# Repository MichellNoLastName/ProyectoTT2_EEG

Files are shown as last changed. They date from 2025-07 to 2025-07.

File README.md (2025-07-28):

# EEG con Sensores Capacitivos de No Contacto

## 🧠 Descripción

Este proyecto consiste en el desarrollo de un prototipo para la adquisición de señales electroencefalográficas (EEG) utilizando sensores capacitivos de no contacto. El sistema incluye una interfaz gráfica desarrollada en LabVIEW que permite visualizar y guardar los datos adquiridos.

El propósito principal es contar con una alternativa no invasiva y cómoda para el monitoreo de actividad cerebral, útil para investigación biomédica y futuros desarrollos en interfaces cerebro-computadora.

## 🔧 Tecnologías utilizadas

- **Lenguaje C** – Programación de microcontroladores.
- **Arduino** – Pruebas iniciales y prototipado.
- **MPLAB X IDE** – Desarrollo en microcontroladores PIC.
- **LabVIEW** – Interfaz gráfica para visualización y almacenamiento de señales.
- **SolidWorks** – Diseño del headset 3D.
- **Autodesk EAGLE** – Diseño de las placas electrónicas.

## 🖼️ Capturas

### Placa electrónica del electrodo en 3D Vista superior
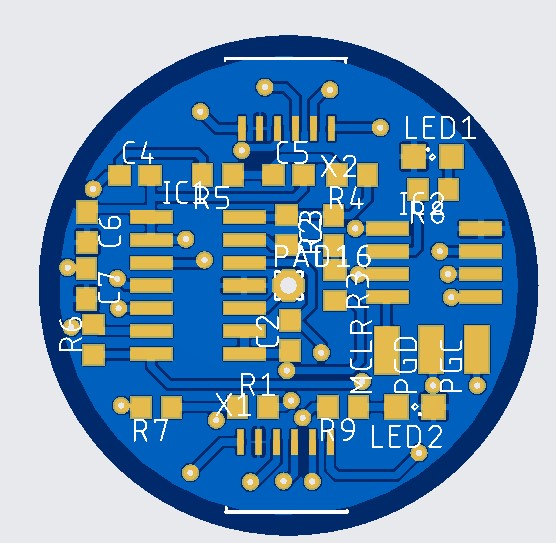
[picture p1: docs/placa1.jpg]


### Placa electrónica del electrodo en 3D Vista inferior
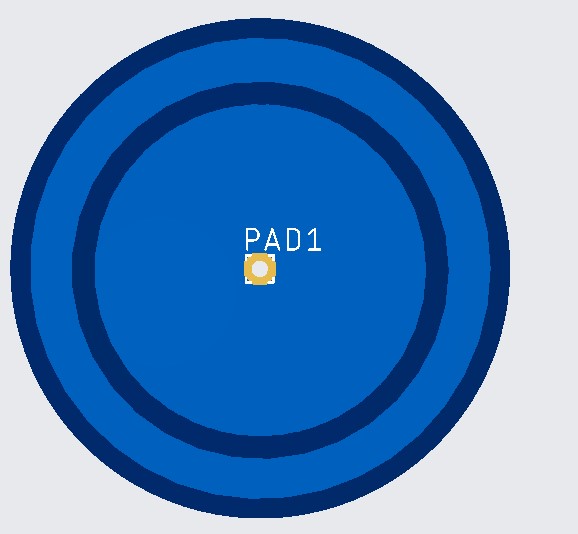
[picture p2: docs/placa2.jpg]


### Placa electrónica del electrodo fabricada
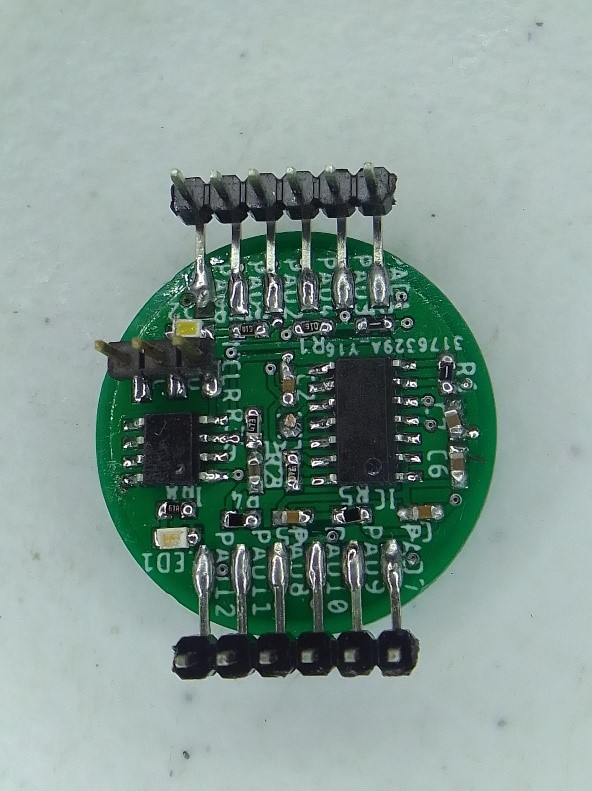
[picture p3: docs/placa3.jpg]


### Headset impreso en 3D
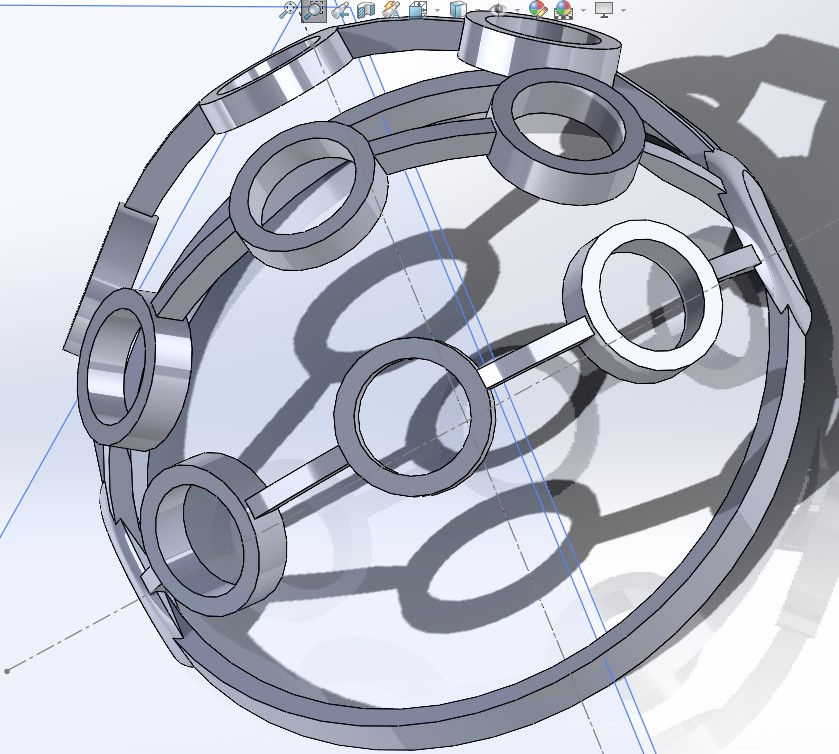
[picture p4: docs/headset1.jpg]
Headset EEG

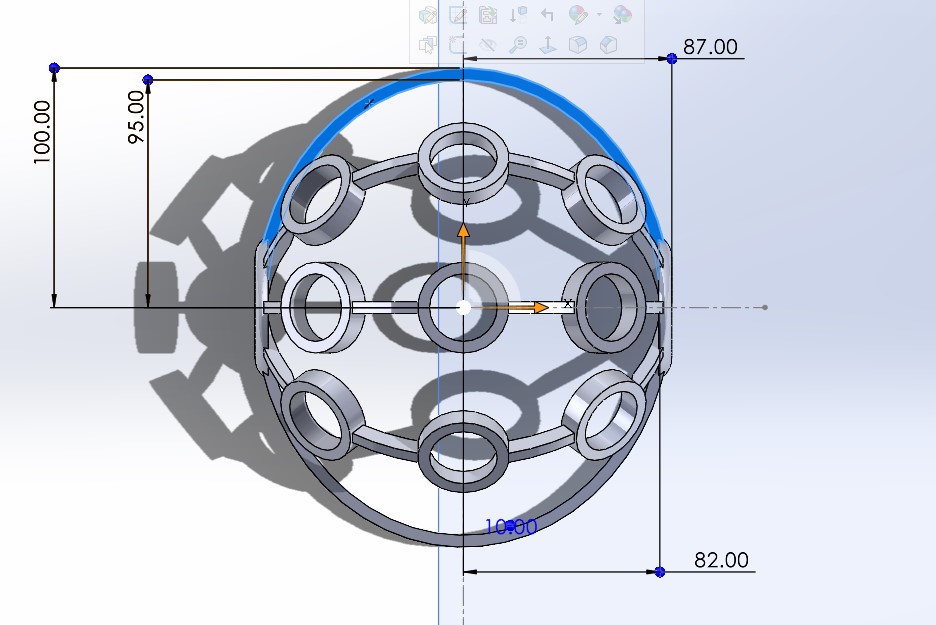
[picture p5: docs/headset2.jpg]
Headset EEG

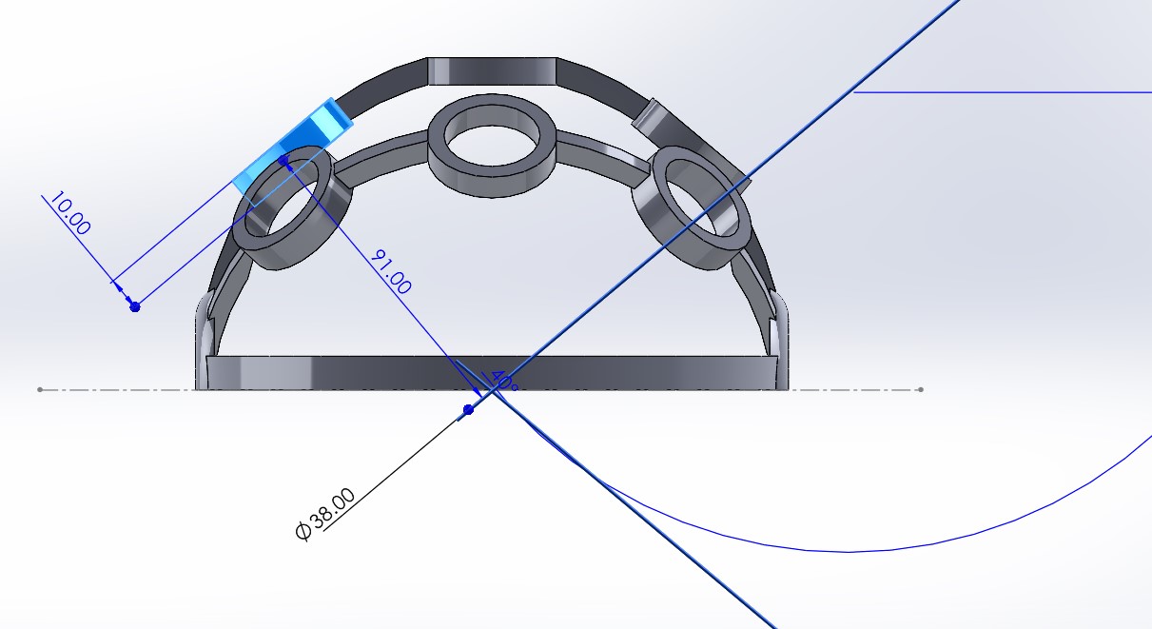
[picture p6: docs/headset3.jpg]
Headset EEG


## Pruebas realizadas
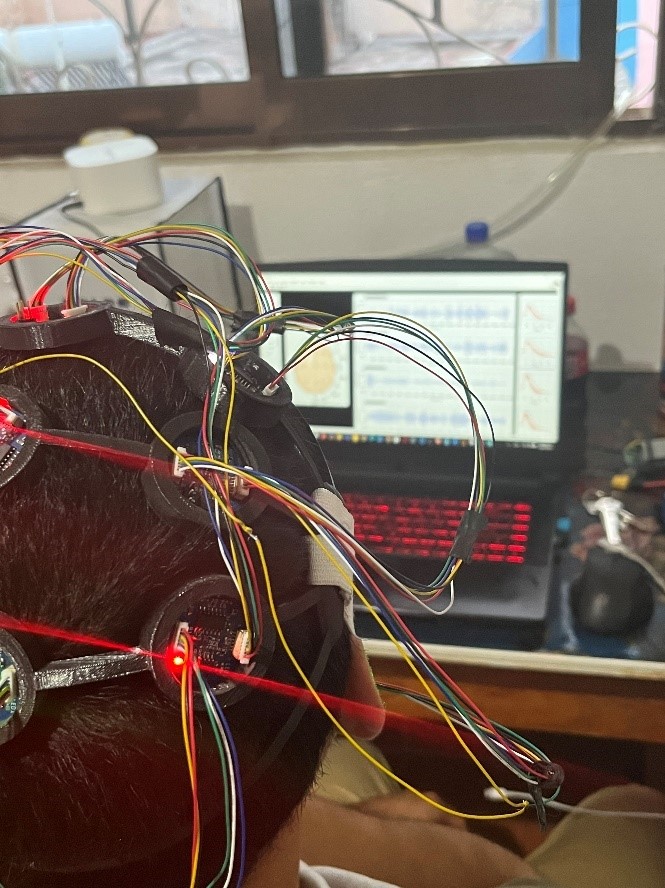
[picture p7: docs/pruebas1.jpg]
Pruebas EEG

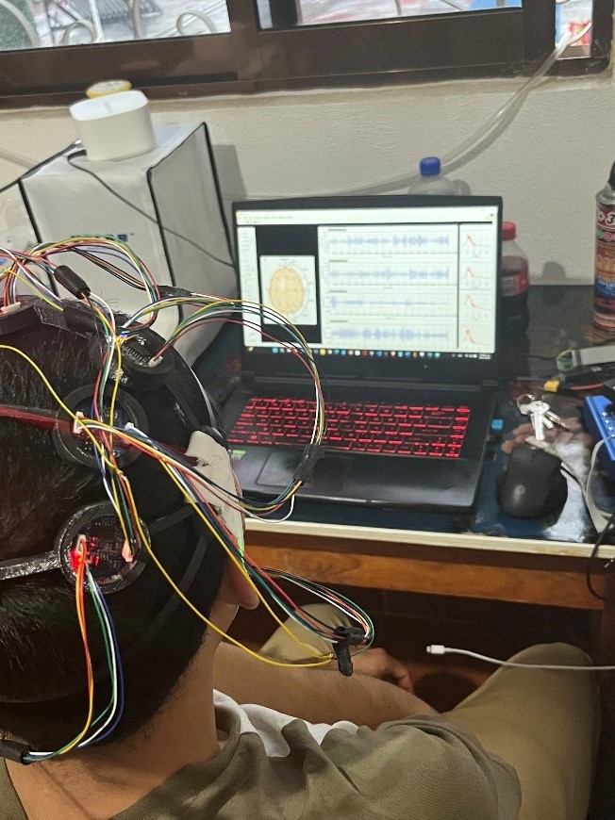
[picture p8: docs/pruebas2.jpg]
Pruebas EEG


### Interfaz de LabVIEW
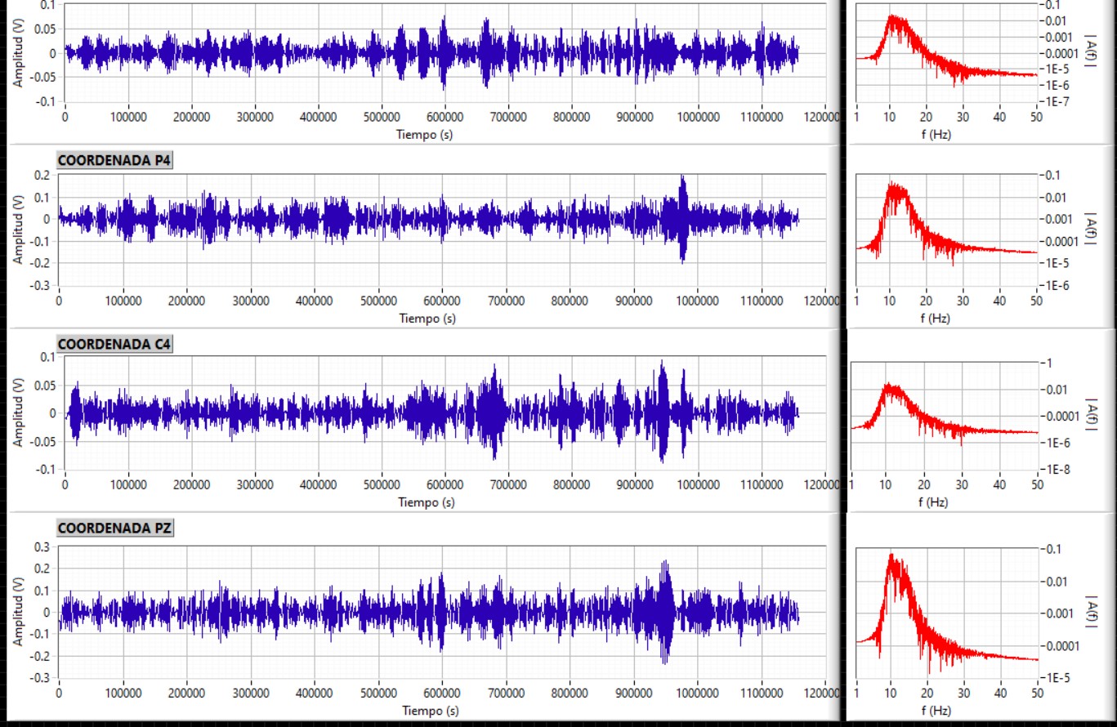
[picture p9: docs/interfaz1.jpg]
Interfaz LabVIEW

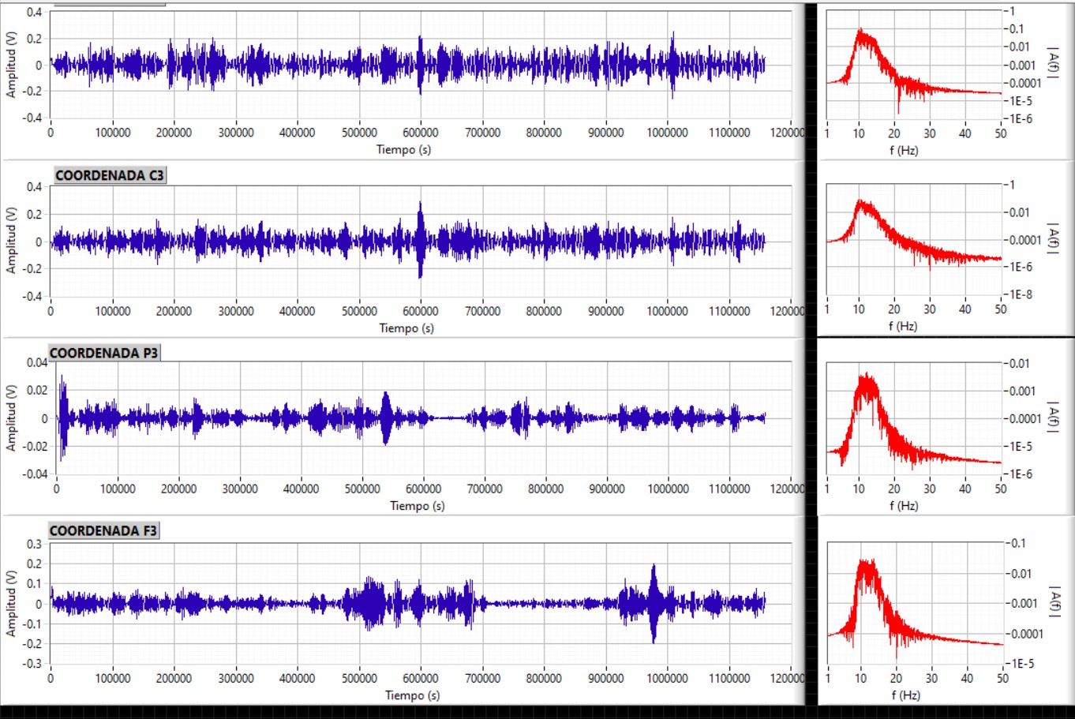
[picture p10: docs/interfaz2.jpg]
Interfaz LabVIEW


## 🚀 Instrucciones básicas de uso

1. **Conecta el sistema**: Alimenta los sensores y conecta el microcontrolador al PC.
2. **Ejecuta la interfaz LabVIEW**: Abre el archivo del proyecto y configura el puerto de comunicación.
3. **Adquiere señales**: Visualiza en tiempo real y guarda los datos cuando sea necesario.
4. **Exporta**: Los datos pueden exportarse como archivo `.csv` para análisis posterior.

## 🤝 Contribuciones

Este proyecto es parte de una tesis de ingeniería, pero estás invitado a contribuir con mejoras, sugerencias o ideas. Abre un Issue o un Pull Request si deseas colaborar.

## 🧾 Licencia

Este proyecto no tiene una licencia formal asignada. Si deseas usarlo con fines educativos o de investigación, puedes hacerlo con atribución.

## 👤 Autor

Michell Alejandro López Sierra  
[GitHub](https://github.com/) | [LinkedIn](https://linkedin.com/) | [Email](ingmichell5101@gmail.com)

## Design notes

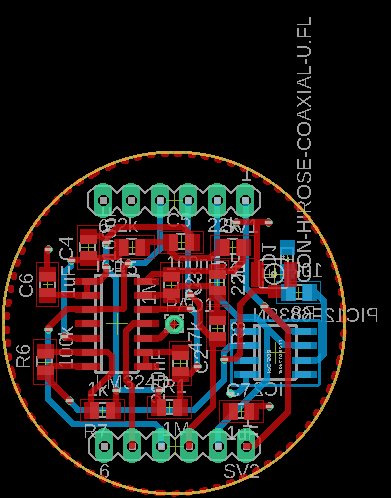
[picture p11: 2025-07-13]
PCB/electrodoPCB.png

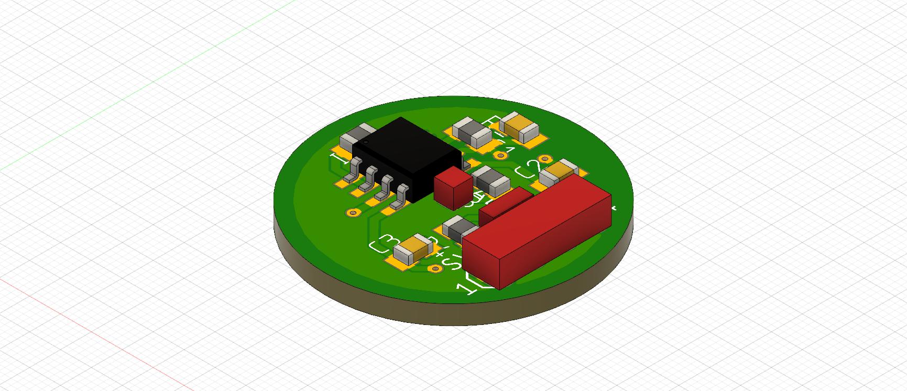
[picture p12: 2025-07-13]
PCB/referencia v1.jpg

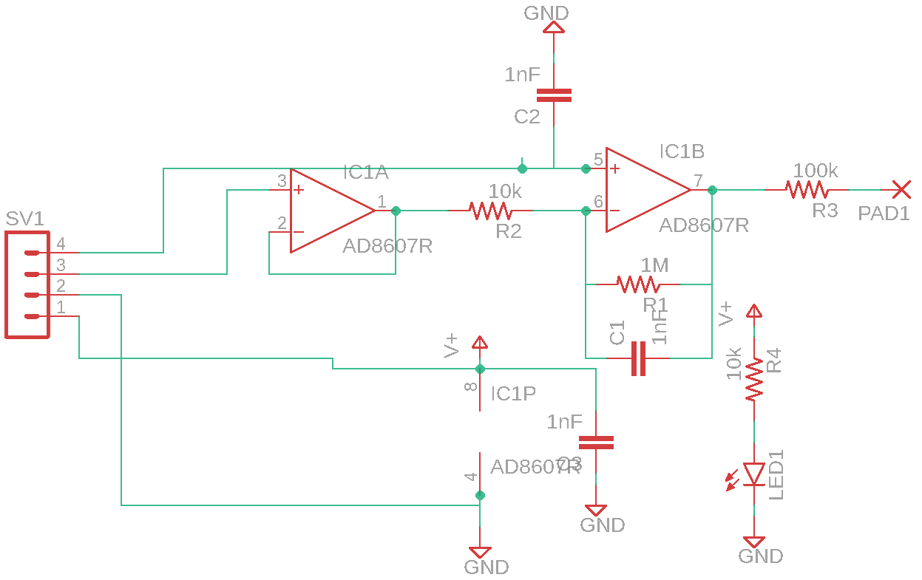
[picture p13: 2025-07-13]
PCB/referenciaCircuit.png

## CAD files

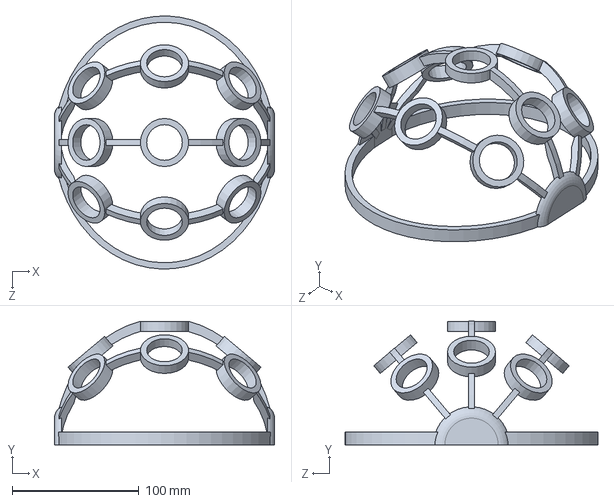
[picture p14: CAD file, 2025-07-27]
Modelos CAD/headsetV2.SLDPRT
174.0 x 97.6 x 199.9 mm

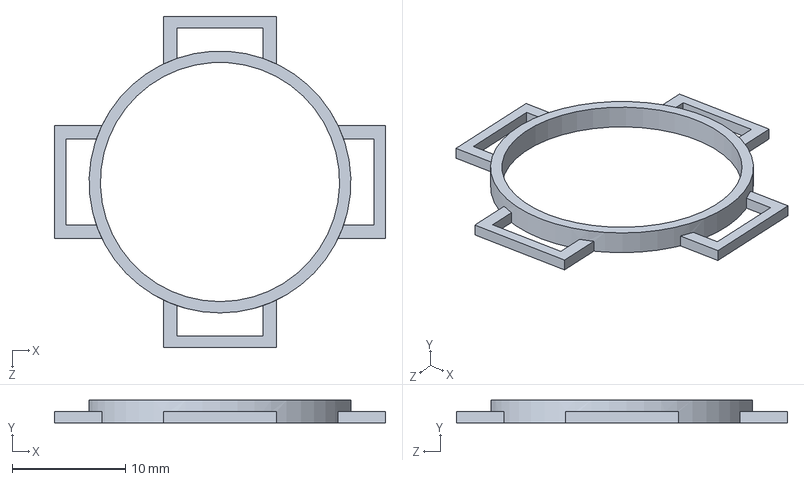
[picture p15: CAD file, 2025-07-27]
Modelos CAD/PortaReferencia.SLDPRT
29.2 x 2.00 x 29.2 mm

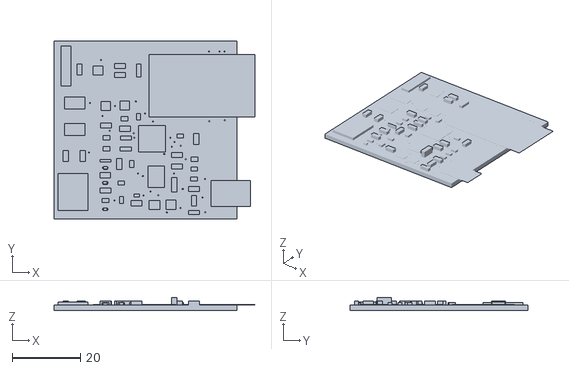
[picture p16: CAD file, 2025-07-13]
PCB/tarjeta v3.stl
58.8 x 52.2 x 3.75

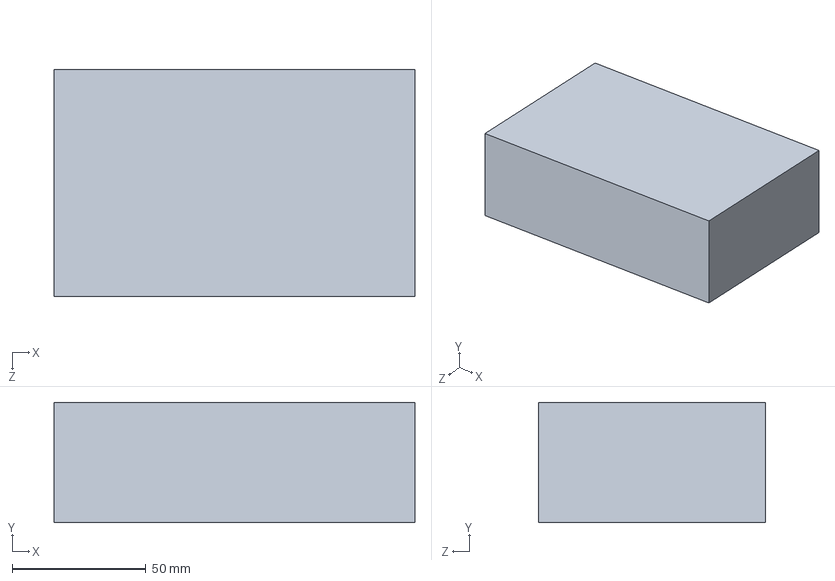
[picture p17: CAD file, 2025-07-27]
Modelos CAD/CajaBase.SLDPRT
135.0 x 45.0 x 85.0 mm

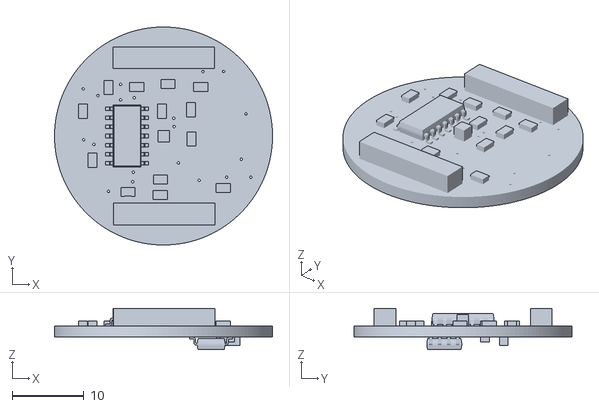
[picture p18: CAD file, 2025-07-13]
PCB/electrodoSTL.stl
30.5 x 30.5 x 5.79

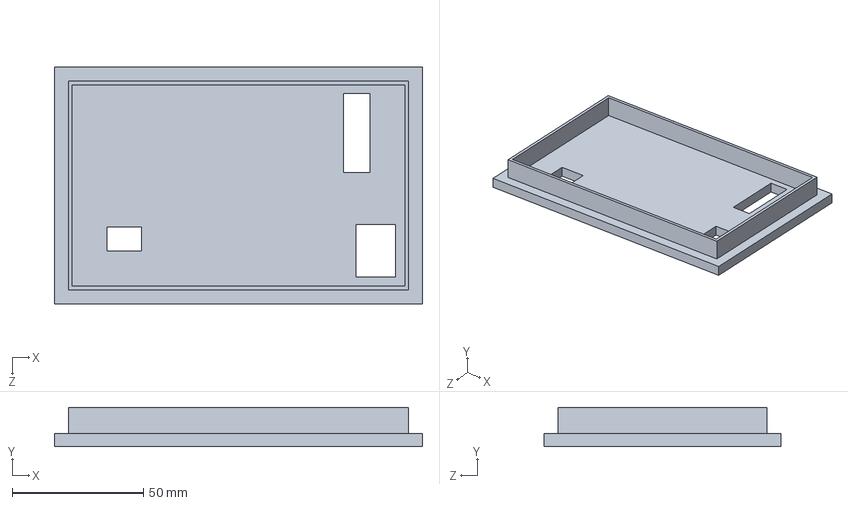
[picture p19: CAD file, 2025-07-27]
Modelos CAD/CAjaTapa.SLDPRT
140.0 x 15.0 x 90.0 mm

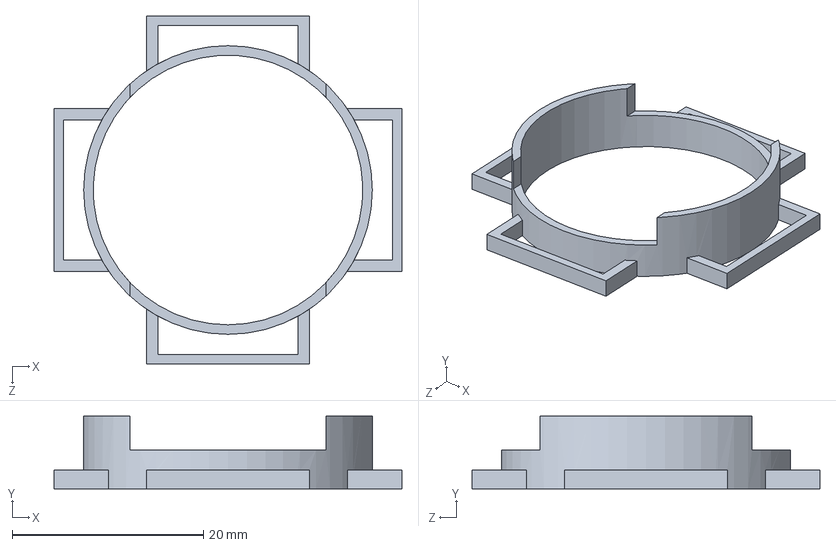
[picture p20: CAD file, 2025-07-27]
Modelos CAD/PortaSensorV.0.SLDPRT
36.4 x 7.62 x 36.4 mm

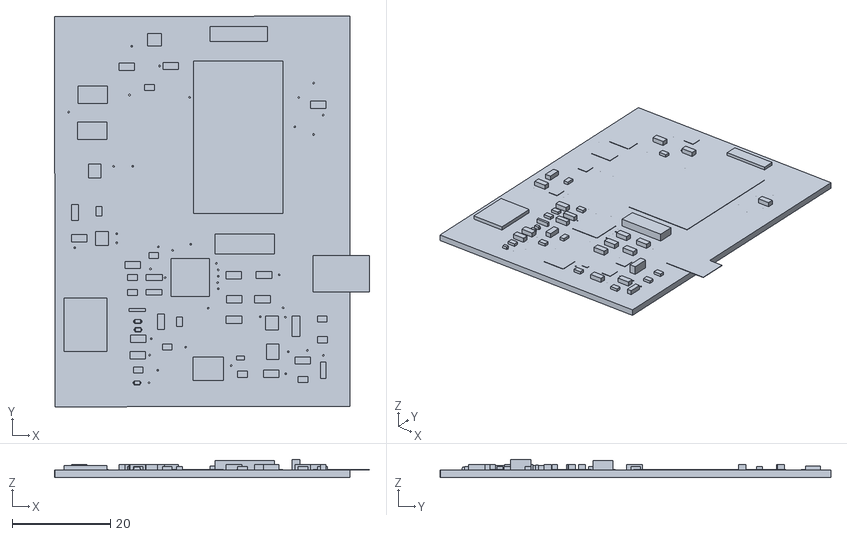
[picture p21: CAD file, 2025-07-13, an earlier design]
PCB/tarjeta v2.stl
64.3 x 79.7 x 3.75

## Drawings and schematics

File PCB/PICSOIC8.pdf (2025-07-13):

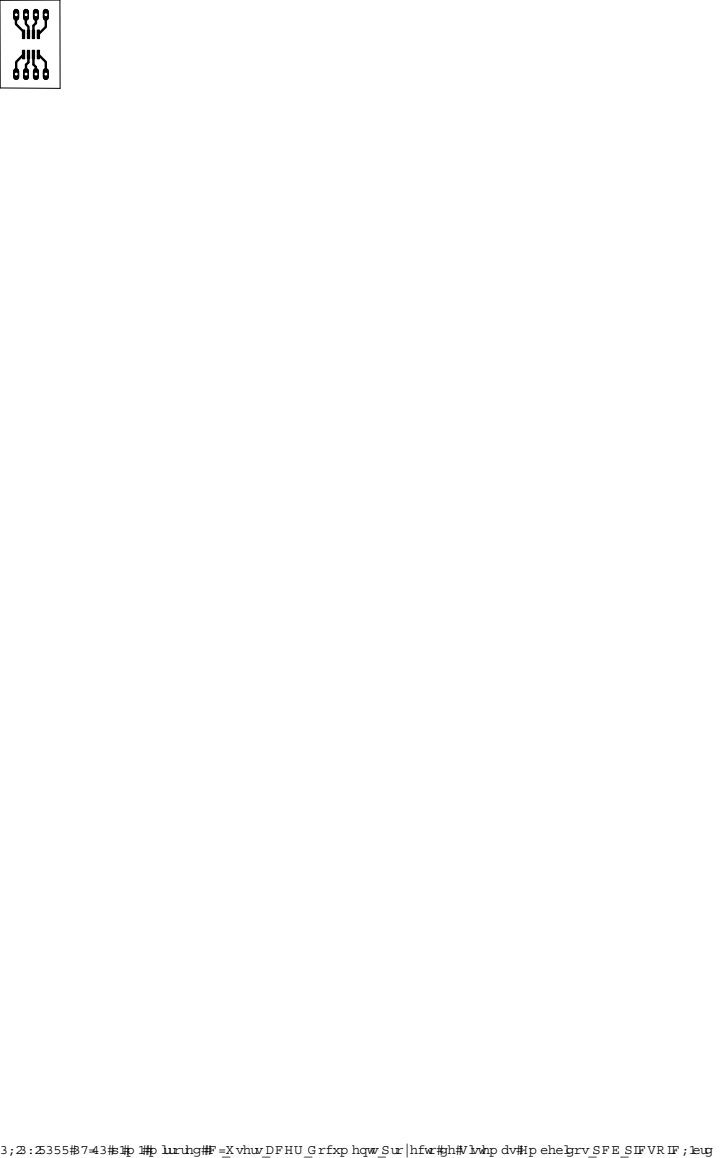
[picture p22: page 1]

08/07/2022 04:10 p. m. mirrored C:\U sers\ACER\D ocum ents\Proyecto de Sistem as Em bebidos\PCB\PICSOIC 8.brd

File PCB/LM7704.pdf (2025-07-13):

## LM324D

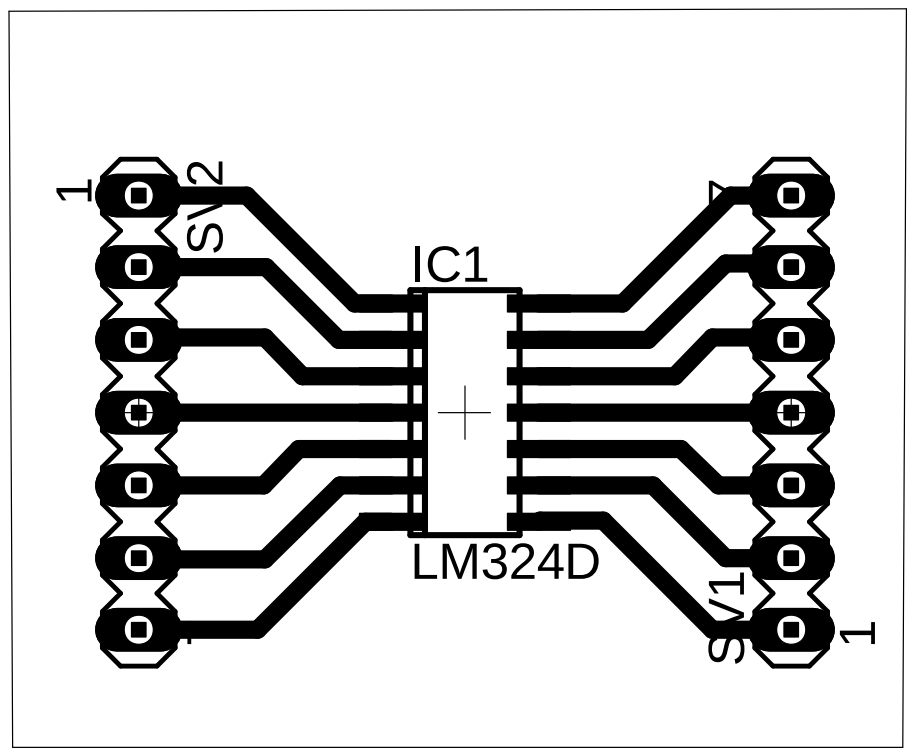
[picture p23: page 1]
SV¹ SV²

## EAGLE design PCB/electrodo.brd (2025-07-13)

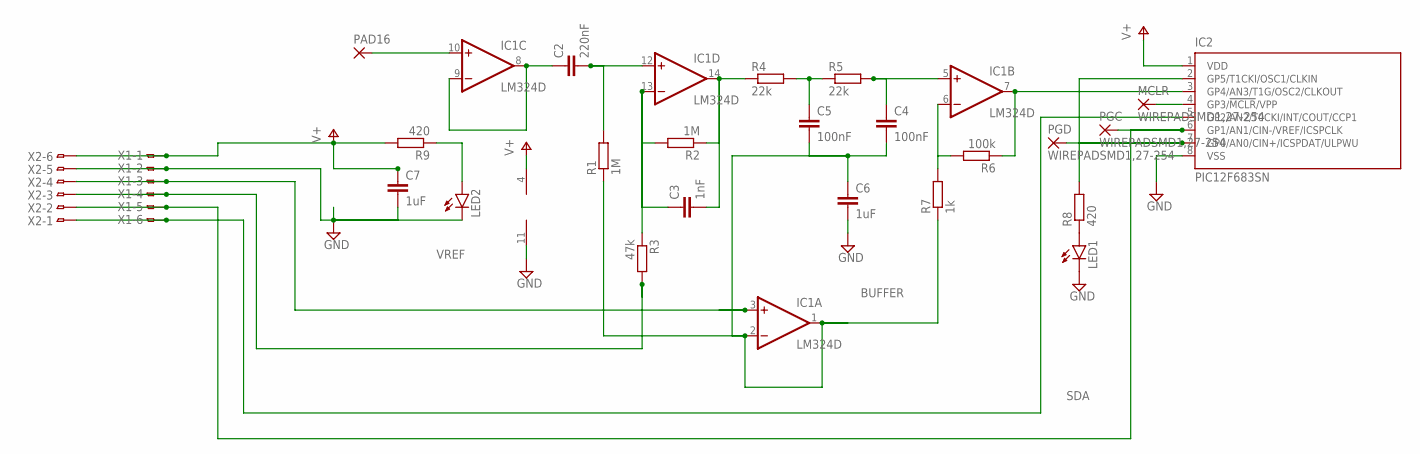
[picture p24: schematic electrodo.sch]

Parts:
C2: 220nF; C0603
C3: 1nF; C0603
C4, C5: 100nF; C0603
C6, C7: 1uF; C0603
IC1: LM324D; SO14
IC2: PIC12F683SN; SO-08
LED1, LED2: LEDSML0805; SML0805
MCLR: WIREPADSMD1,27-254; SMD1,27-2,54
PAD16: 1,6/0,9
PGC: WIREPADSMD1,27-254; SMD1,27-2,54
PGD: WIREPADSMD1,27-254; SMD1,27-2,54
R1, R2: 1M; R0603
R3: 47k; R0603
R4, R5: 22k; R0603
R6: 100k; R0603
R7: 1k; R0603
R8, R9: 420; R0603
X1, X2: FH12-08S-1SH

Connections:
BUFFER: C4.2, C5.2, C6.1, IC1.1 (OUT), IC1.2 (-IN), R1.1, R7.1
GND: C6.2, C7.2, IC1.11 (V-), IC2.8 (VSS), LED1.C, LED2.C, X1.2, X2.5
unnamed: IC2.2 (GP5/T1CKI/OSC1/CLKIN), R8.2
unnamed: C4.1, IC1.5 (+IN), R5.2
unnamed: C2.2, IC1.12 (+IN), R1.2
unnamed: IC1.7 (OUT), IC2.3 (GP4/AN3/T1G/OSC2/CLKOUT), R6.1
unnamed: LED1.A, R8.1
unnamed: C3.2, IC1.14 (OUT), R2.1, R4.1
unnamed: LED2.A, R9.1
unnamed: IC2.4 (GP3/!MCLR!/VPP), MCLR.1
unnamed: C5.1, R4.2, R5.1
unnamed: IC1.6 (-IN), R6.2, R7.2
unnamed: IC1.10 (+IN), PAD16.1
unnamed: C2.1, IC1.8 (OUT), IC1.9 (-IN)
unnamed: C3.1, IC1.13 (-IN), R2.2, R3.1
unnamed: IC2.7 (GP0/AN0/CIN+/ICSPDAT/ULPWU), PGD.1
REFGROUND: R3.2, X1.4, X2.3
SCL: IC2.6 (GP1/AN1/CIN-/VREF/ICSPCLK), PGC.1, X1.5, X2.2
SDA: IC2.5 (GP2/AN2/T0CKI/INT/COUT/CCP1), X1.6, X2.1
V+: C7.1, IC1.4 (V+), IC2.1 (VDD), R9.2, X1.1, X2.6
VREF: IC1.3 (+IN), X1.3, X2.4

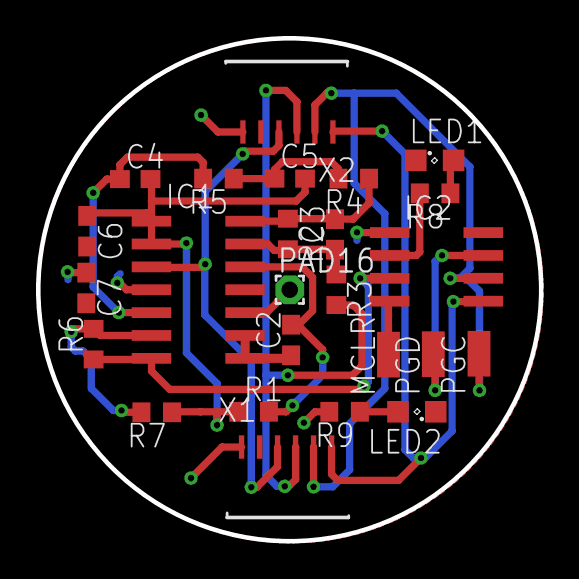
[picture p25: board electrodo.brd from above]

Board: 2 copper layers, 27.9 x 27.9 mm, 25 parts (0 on the bottom side), 21 nets.

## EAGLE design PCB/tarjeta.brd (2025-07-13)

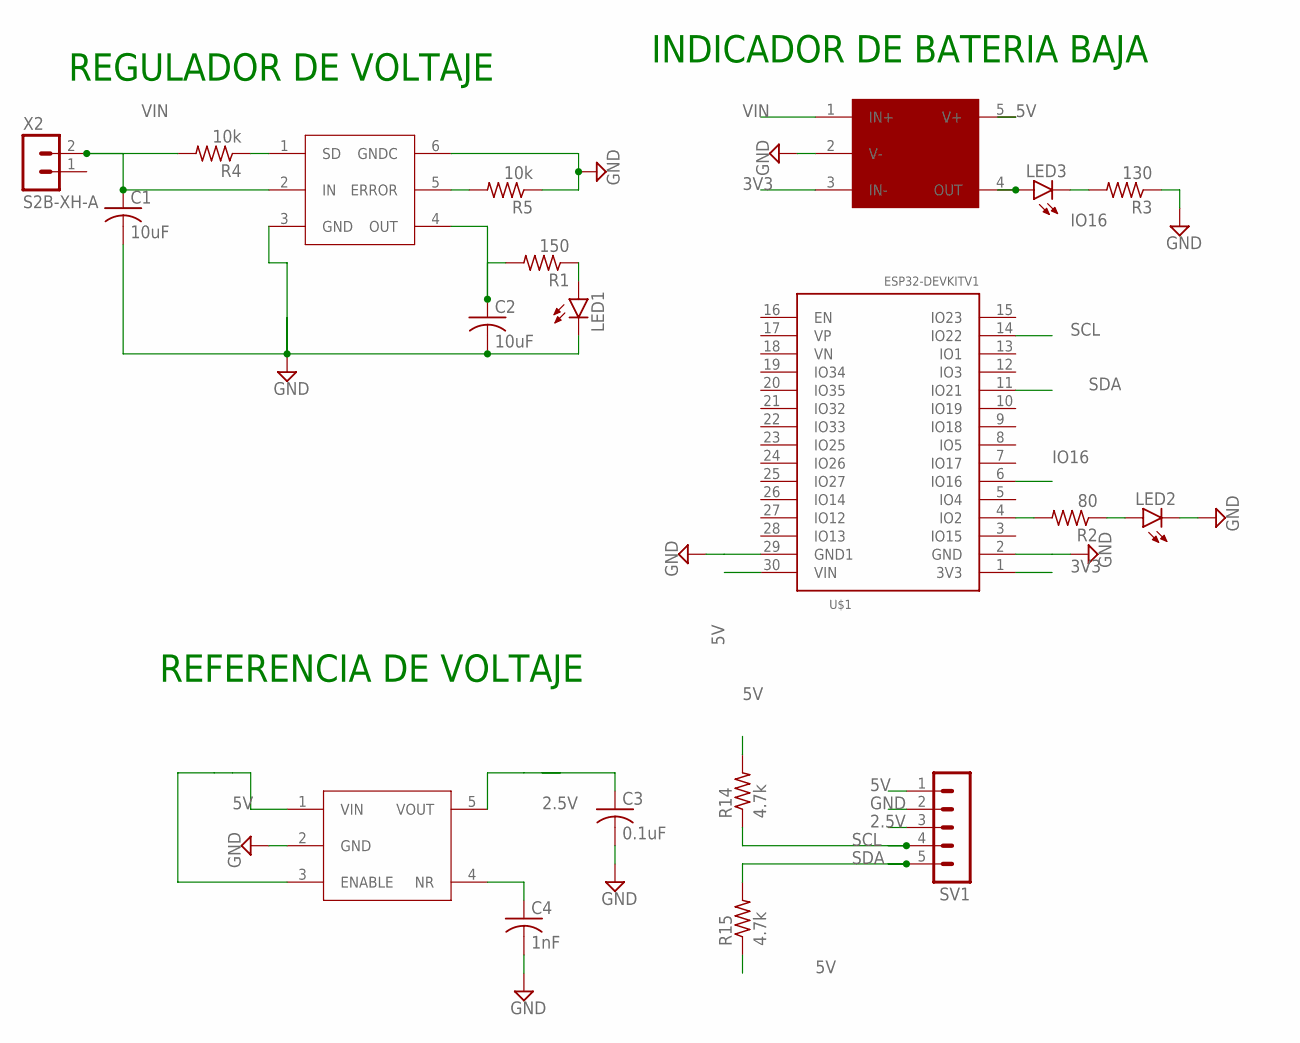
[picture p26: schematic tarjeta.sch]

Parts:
.: LP3872ES; TO263-5
C1, C2: 10uF; C0603
C3: 0.1uF; C0603
C4: 1nF; C0603
LED1, LED2, LED3: LEDSML0805; SML0805
R1: 150; R0603
R2: 80; R0603
R3: 130; R0603
R4, R5: 10k; R0603
R14, R15: 4.7k; R0603
SV1: MA05-1
U$1: ESP32DEVKITV1; ESP32-DEVKITV1
U$3: REG113; SOT23-5
U$4: TL081-5; SOT23-5
X2: S2B-XH-A

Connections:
2.5V: C3.1, SV1.3, U$3.5 (VOUT)
3V3: U$1.1 (3V3), U$4.3 (IN-)
5V: R14.2, R15.1, SV1.1, U$1.30 (VIN), U$3.1 (VIN), U$3.3 (ENABLE), U$4.5 (V+)
GND: ..3 (GND), ..6 (GNDC), C1.2, C2.2, C3.2, C4.2, LED1.C, LED2.C, R3.1, R5.1, SV1.2, U$1.2 (GND), U$1.29 (GND1), U$3.2 (GND), U$4.2 (V-)
IO16: LED3.C, R3.2, U$1.6 (IO16)
unnamed: LED1.A, R1.1
unnamed: LED3.A, U$4.4 (OUT)
unnamed: R2.2, U$1.4 (IO2)
unnamed: LED2.A, R2.1
unnamed: ..1 (SD), R4.1
unnamed: C4.1, U$3.4 (NR)
unnamed: ..5 (ERROR), R5.2
unnamed: ..4 (OUT), C2.1, R1.2
SCL: R14.1, SV1.4, U$1.14 (IO22)
SDA: R15.2, SV1.5, U$1.11 (IO21)
VIN: ..2 (IN), C1.1, R4.2, U$4.1 (IN+), X2.2

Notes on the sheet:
REGULADOR DE VOLTAJE
REFERENCIA DE VOLTAJE
INDICADOR DE BATERIA BAJA

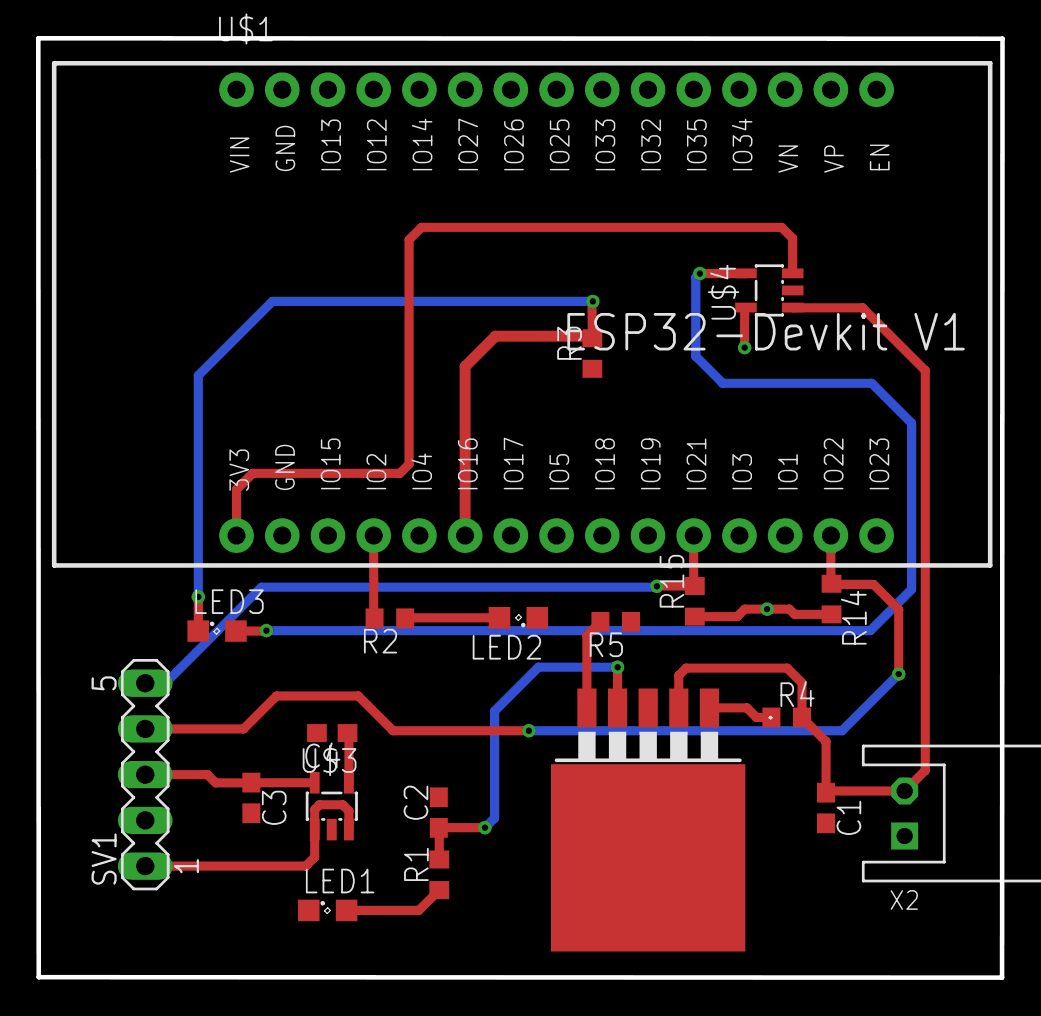
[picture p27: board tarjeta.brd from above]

Board: 2 copper layers, 53.6 x 52.2 mm, 20 parts (0 on the bottom side), 16 nets.

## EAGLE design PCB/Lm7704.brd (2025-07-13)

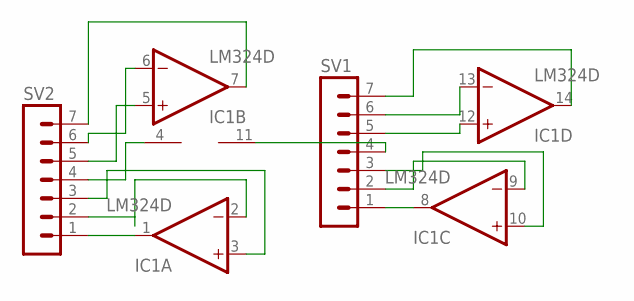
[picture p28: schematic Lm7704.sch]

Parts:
IC1: LM324D; SO14
SV1, SV2: MA07-1

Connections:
unnamed: IC1.1 (OUT), SV2.1
unnamed: IC1.2 (-IN), SV2.2
unnamed: IC1.3 (+IN), SV2.3
unnamed: IC1.4 (V+), SV2.4
unnamed: IC1.5 (+IN), SV2.5
unnamed: IC1.6 (-IN), SV2.6
unnamed: IC1.7 (OUT), SV2.7
unnamed: IC1.8 (OUT), SV1.1
unnamed: IC1.9 (-IN), SV1.2
unnamed: IC1.10 (+IN), SV1.3
unnamed: IC1.11 (V-), SV1.4
unnamed: IC1.12 (+IN), SV1.5
unnamed: IC1.13 (-IN), SV1.6
unnamed: IC1.14 (OUT), SV1.7

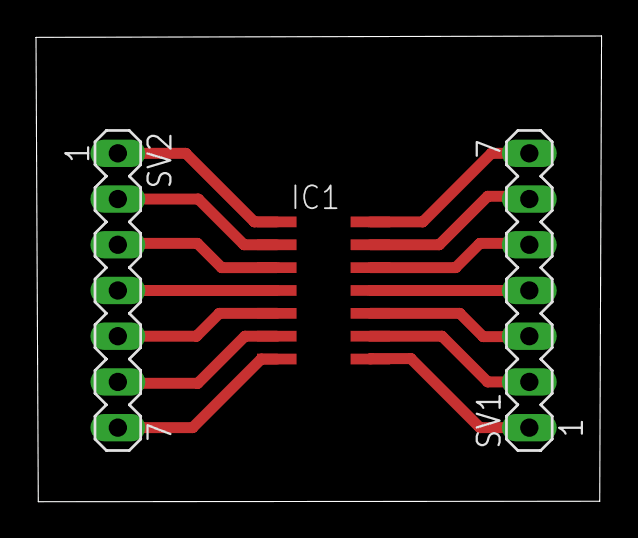
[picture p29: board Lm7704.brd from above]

Board: 2 copper layers, 31.4 x 25.9 mm, 3 parts (0 on the bottom side), 14 nets.

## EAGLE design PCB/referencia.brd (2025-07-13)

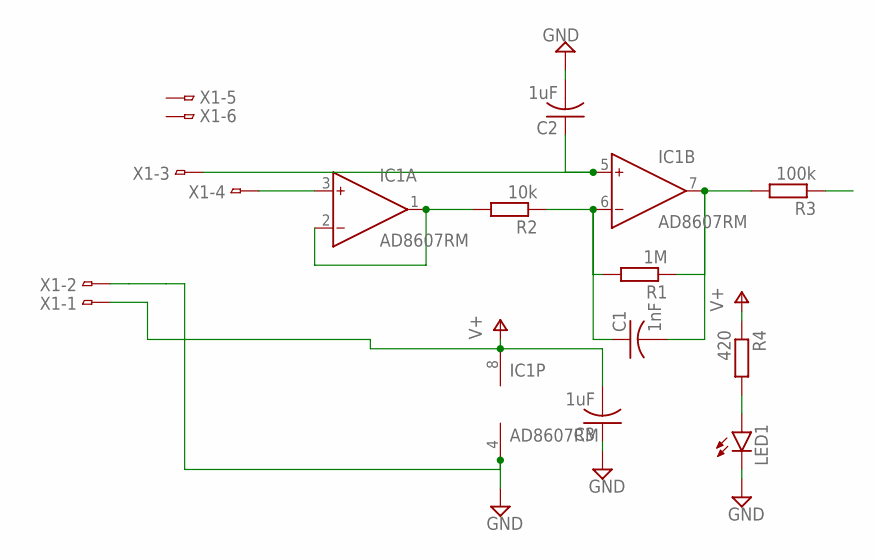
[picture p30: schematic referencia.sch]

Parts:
C1: 1nF; C0603
C2, C3: 1uF; C0603
IC1: AD8607RM; MSOP08
LED1: LEDSML0805; SML0805
R1: 1M; R0603
R2: 10k; R0603
R3: 100k; R0603
R4: 420; R0603
X1: FH12-08S-1SH

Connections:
GND: C2.2, C3.1, IC1.4 (V-), LED1.C, X1.2
unnamed: IC1.1 (OUT), IC1.2 (IN-), R2.2
unnamed: C1.1, IC1.6 (IN-), R1.2, R2.1
unnamed: C1.2, IC1.7 (OUT), R1.1, R3.2
unnamed: IC1.3 (IN+), X1.4
unnamed: C2.1, IC1.5 (IN+), X1.3
unnamed: LED1.A, R4.2
REF: R3.1
V+: C3.2, IC1.8 (V+), R4.1, X1.1

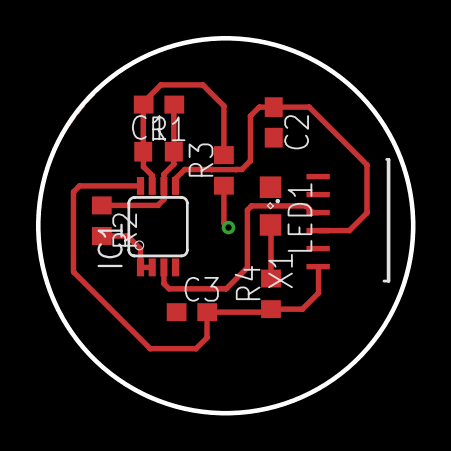
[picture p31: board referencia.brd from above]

Board: 2 copper layers, 20.8 x 20.8 mm, 10 parts (0 on the bottom side), 8 nets.

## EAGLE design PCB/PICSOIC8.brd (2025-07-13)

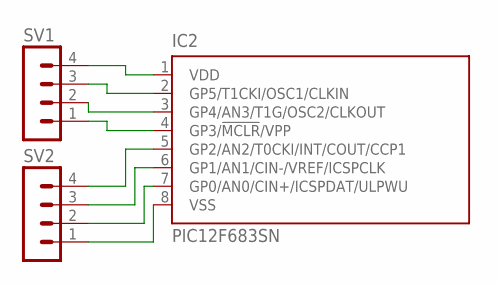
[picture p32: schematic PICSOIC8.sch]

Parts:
IC2: PIC12F683SN; SO-08
SV1, SV2: MA04-1

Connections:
unnamed: IC2.1 (VDD), SV1.4
unnamed: IC2.2 (GP5/T1CKI/OSC1/CLKIN), SV1.3
unnamed: IC2.3 (GP4/AN3/T1G/OSC2/CLKOUT), SV1.2
unnamed: IC2.4 (GP3/!MCLR!/VPP), SV1.1
unnamed: IC2.5 (GP2/AN2/T0CKI/INT/COUT/CCP1), SV2.4
unnamed: IC2.6 (GP1/AN1/CIN-/VREF/ICSPCLK), SV2.3
unnamed: IC2.7 (GP0/AN0/CIN+/ICSPDAT/ULPWU), SV2.2
unnamed: IC2.8 (VSS), SV2.1

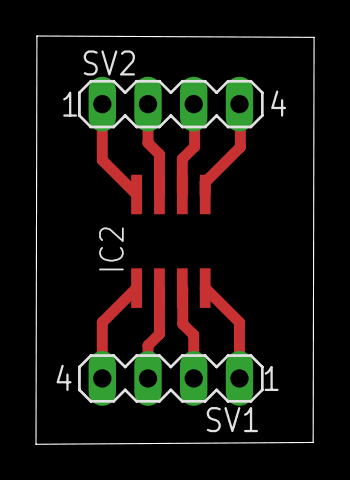
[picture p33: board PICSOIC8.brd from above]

Board: 2 copper layers, 15.4 x 22.7 mm, 3 parts (0 on the bottom side), 8 nets.

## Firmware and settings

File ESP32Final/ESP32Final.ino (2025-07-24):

#include <Wire.h>
#include <BluetoothSerial.h>
#include <Filters.h>

BluetoothSerial SerialBT;

#if !defined(CONFIG_BT_ENABLED) || !defined(CONFIG_BLUEDROID_ENABLED)
  #error Bluetooth is not enabled! Please run `make menuconfig` to enable it
#endif

// ---------- Variables Globales ----------
volatile int interruptCounter = 0;
hw_timer_t* timer = NULL;
portMUX_TYPE timerMux = portMUX_INITIALIZER_UNLOCKED;

bool acquisitionEnabled = false;
unsigned int adcValue = 0;
unsigned int adcBuffer[20];
unsigned int detectedDevices[20];
int totalDevices = 0;
String btMessage = "";

unsigned int msb = 0, lsb = 0;
int incomingByte = 0;

// ---------- Interrupciones ----------
void IRAM_ATTR onTimer() {
  portENTER_CRITICAL_ISR(&timerMux);
  interruptCounter++;
  portEXIT_CRITICAL_ISR(&timerMux);
}

void decrementInterruptCounter() {
  portENTER_CRITICAL(&timerMux);
  interruptCounter--;
  portEXIT_CRITICAL(&timerMux);
}

// ---------- Busqueda de Dispositivos ----------
void searchI2CDevices() {
  totalDevices = 0;
  for (int addr = 0; addr < 128; addr++) {
    Wire.beginTransmission(addr);
    uint8_t error = Wire.endTransmission();
    if (error == 0) {
      detectedDevices[totalDevices++] = addr;
    }
  }
  Serial.println("Dispositivos encontrados: " + String(totalDevices));
}

unsigned int readADCFromDevice(int address) {
  Wire.requestFrom(address, 2);
  while (Wire.available()) {
    msb = Wire.read();
    lsb = Wire.read();
  }
  return (msb << 8) | lsb;
}

void sendByteToDevice(int address, bool value) {
  Wire.beginTransmission(address);
  Wire.write(byte(value));
  Wire.endTransmission();
}

void sendBTData(unsigned int values[], int count) {
  btMessage = "";
  for (int i = 0; i < count; i++) {
    btMessage += String(values[i]);
    if (i < count - 1) {
      btMessage += ",";
    }
  }
  SerialBT.println(btMessage);
  Serial.println(btMessage);
}

// ---------- Setup ----------
void setup() {
  Serial.begin(9600);
  Wire.begin();
  Wire.setClock(400000);  // I2C a 400 kHz
  SerialBT.begin("ESP32");
  Serial.println("Bluetooth activado");

  pinMode(2, OUTPUT);
  digitalWrite(2, HIGH);
  delay(1000);
  digitalWrite(2, LOW);
  //searchI2CDevices(); //DEBUG

  // Configuración del temporizador
  timer = timerBegin(0, 80, true);               // 80 prescaler -> 1 µs (con 80 MHz APB clock)
  timerAttachInterrupt(timer, &onTimer, true);
  timerAlarmWrite(timer, 5000, true);            // Cada 5000 µs (5 ms)
  timerAlarmEnable(timer);
}

// ---------- Loop Principal ----------
void loop() {
  if (interruptCounter > 0) {
    decrementInterruptCounter();

    if (SerialBT.available()) {
      incomingByte = SerialBT.read();

      switch (incomingByte) {
        case 'R':
        case 'D':
          searchI2CDevices();
          delay(100);
          if (totalDevices == 2 || totalDevices == 9) {
            sendBTData(detectedDevices, totalDevices);
            delay(1000);
            acquisitionEnabled = true;
          } else {
            SerialBT.println("ERROR");
          }
          break;

        case 'P':
          acquisitionEnabled = false;
          break;

        default:
          digitalWrite(2, HIGH);
          break;
      }

      Serial.println("Comando recibido: " + String((char)incomingByte));
    }

    else if (acquisitionEnabled) {
      for (int i = 0; i < totalDevices; i++) {
        adcBuffer[i] = readADCFromDevice(detectedDevices[i]);
      }
      sendBTData(adcBuffer, totalDevices);
    }
  }
}

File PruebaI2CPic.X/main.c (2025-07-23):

/*
 * File:   main.c
 * Author: Admin
 *
 * Created on 17 de junio de 2024, 08:01 PM
 */


#include <xc.h>

// Configuraciones del compilador
#pragma config FOSC = INTOSC    // Oscilador interno
#pragma config WDTE = OFF       // Watchdog Timer deshabilitado
#pragma config PWRTE = OFF      // Power-up Timer deshabilitado
#pragma config MCLRE = OFF      // MCLR pin deshabilitado
#pragma config CP = OFF         // Código de protección deshabilitado
#pragma config BOREN = ON       // Brown-out Reset habilitado
#pragma config CLKOUTEN = OFF   // CLKOUT deshabilitado
#pragma config IESO = OFF       // Oscilador interno/externo deshabilitado
#pragma config FCMEN = OFF      // Fail-Safe Clock Monitor deshabilitado

#pragma config WRT = OFF
#pragma config PLLEN = ON
#pragma config STVREN = ON
#pragma config BORV = LO
#pragma config LVP = OFF

#define _XTAL_FREQ 16000000  // Frecuencia del oscilador interno (16 MHz)

int received_data = 0x00;

void config(void){
    OSCCON = 0x78;  // Seleccionar HFINTOSC con frecuencia 16 MHz
    OSCTUNE = 0x00; // No hay ajuste adicional necesario
    
    TRISAbits.TRISA0 = 0; // LED
    TRISAbits.TRISA1 = 1;  // SCL1 como entrada
    TRISAbits.TRISA2 = 1;  // SDA1 como entrada
    TRISAbits.TRISA4 = 1; //Lectura ADC
    
    ANSELA = 0x10;   // RA4 como entrada analógica
    
    PORTA = 0x00;
    
    // Configuración del MSSP para modo esclavo I2C
    SSP1CON1bits.SSPM = 0b0110; // Modo I2C esclavo con direccion 7 bits
    //Usadas: 0x10,0x20,0x30,0x40,0x50,0x60,0x68,0x70,0x76
    SSP1ADD = 0x76;             // Dirección del esclavo
    SSP1CON1bits.SSPEN = 1;     // Habilitar el módulo MSSP

    // Habilitar interrupciones
    SSP1IF = 0;     // Limpiar bandera de interrupción del MSSP
    SSP1IE = 1;     // Habilitar interrupciones del MSSP
    PEIE = 1;       // Habilitar interrupciones periféricas
    GIE = 1;        // Habilitar interrupciones globales
}

void config_ADC(void) {
    // Configuración del canal ADC y habilitación del módulo ADC
    FVRCONbits.FVREN = 1;       // Encender FVR
    FVRCONbits.ADFVR = 0b01;    // 1.024 V como referencia ADC
    __delay_ms(5);              // Esperar estabilización FVR (mínimo 1 ms recomendado)
    
    ADCON0bits.CHS = 0b0011;  // Seleccionar el canal AN3 (RA4)
    ADCON0bits.ADON = 1;      // Habilitar el ADC
    
    // Configuración del ADCON1
    ADCON1bits.ADCS = 0b110;  // Prescaler FOSC/64
    ADCON1bits.ADFM = 1;      // Justificación a la derecha
    ADCON1bits.ADPREF = 0b11; // Referencia de voltaje VDD
}

void __interrupt() ISR(void) {
    
    if(PIR1bits.SSP1IF == 1){
        PIR1bits.SSP1IF = 0;
        if(SSP1STATbits.D_nA == 0){
            received_data = SSP1BUF;
            ADCON0bits.ADGO = 1;
            if(received_data == 0x00 ){;}
            if(SSP1STATbits.R_nW == 1){
                SSP1BUF = ADRESH;
                SSP1CON1bits.CKP = 1;
            }
        }
        else{
            if(SSP1STATbits.R_nW == 1 && SSP1CON2bits.ACKSTAT == 0){
                SSP1BUF = ADRESL;
                SSP1CON1bits.CKP = 1;
            }
            if(SSP1STATbits.R_nW == 0){
                received_data = SSP1BUF;
            }
        }
    }
}

void blinkLed(void){
    PORTAbits.RA0 = 0;
    __delay_ms(500);
    PORTAbits.RA0 = 1;
    __delay_ms(500);
}

void main(void) {
    config();
    config_ADC();
    while(1){
        blinkLed();
    }
}

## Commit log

2025-07-08 Version preliminar de EEG
2025-07-10 Version de prueba con implementacion de Queues
2025-07-12 Se comienza construccion de los waveforms
2025-07-13 Version preliminar de entrega de proyecto
    [ESP32-S2_Thing_Plus.sch, Lm7704.brd, Lm7704.sch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]
2025-07-14 Version final de interfaz LabView V1
2025-07-18 Cambio de filtros, integracion de notch y butterworth y smoothhig
2025-07-23 Se configura los electrodos para con una referencia de voltaje de 1.024V
2025-07-23 Se agrega conversion de V a uV
2025-07-24 Se agrega capacidad de guardar la señales
2025-07-24 Version final para presentacion
    [Base.xlsx]
2025-07-27 Se agregan modelos CAD
    [CAjaTapa.SLDPRT, CajaBase.SLDPRT, PortaReferencia.SLDPRT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]
2025-07-28 Se agregan imagenes para el README.me
2025-07-28 Creacion de README.md

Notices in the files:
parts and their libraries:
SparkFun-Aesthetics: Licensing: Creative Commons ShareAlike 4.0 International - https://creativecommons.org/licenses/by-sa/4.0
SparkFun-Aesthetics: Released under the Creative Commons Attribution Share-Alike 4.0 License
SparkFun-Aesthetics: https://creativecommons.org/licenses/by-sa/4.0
